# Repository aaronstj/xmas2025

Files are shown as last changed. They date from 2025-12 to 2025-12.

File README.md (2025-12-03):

# xmas2025

This is the code and schematics/PCB design for the 2025 Christmas ornament.

The ornament runs on an ATTINY85 microcontroller running the Micronucleus bootloader.  The code runs on the Arduino platform using the ATTinyCore.

## The top of the ornament looks like a USB?
It is! You can reprogram the ornament through the usb.  Download the ATTinyCore for Arduino, set your board to "ATTiny85 (Micronucleus/Digispark)".  When uploading new code, insert the ESB end of the ornament into your USB port, component-side up - it's not quite the same right size, so it may take some wiggling and careful holding.  You will likely need to use `Zadig` to install the `libusbK` driver.

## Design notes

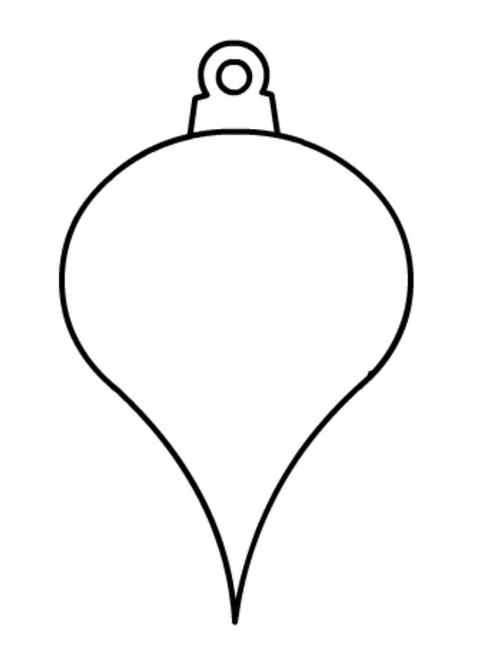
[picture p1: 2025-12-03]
ornament.png

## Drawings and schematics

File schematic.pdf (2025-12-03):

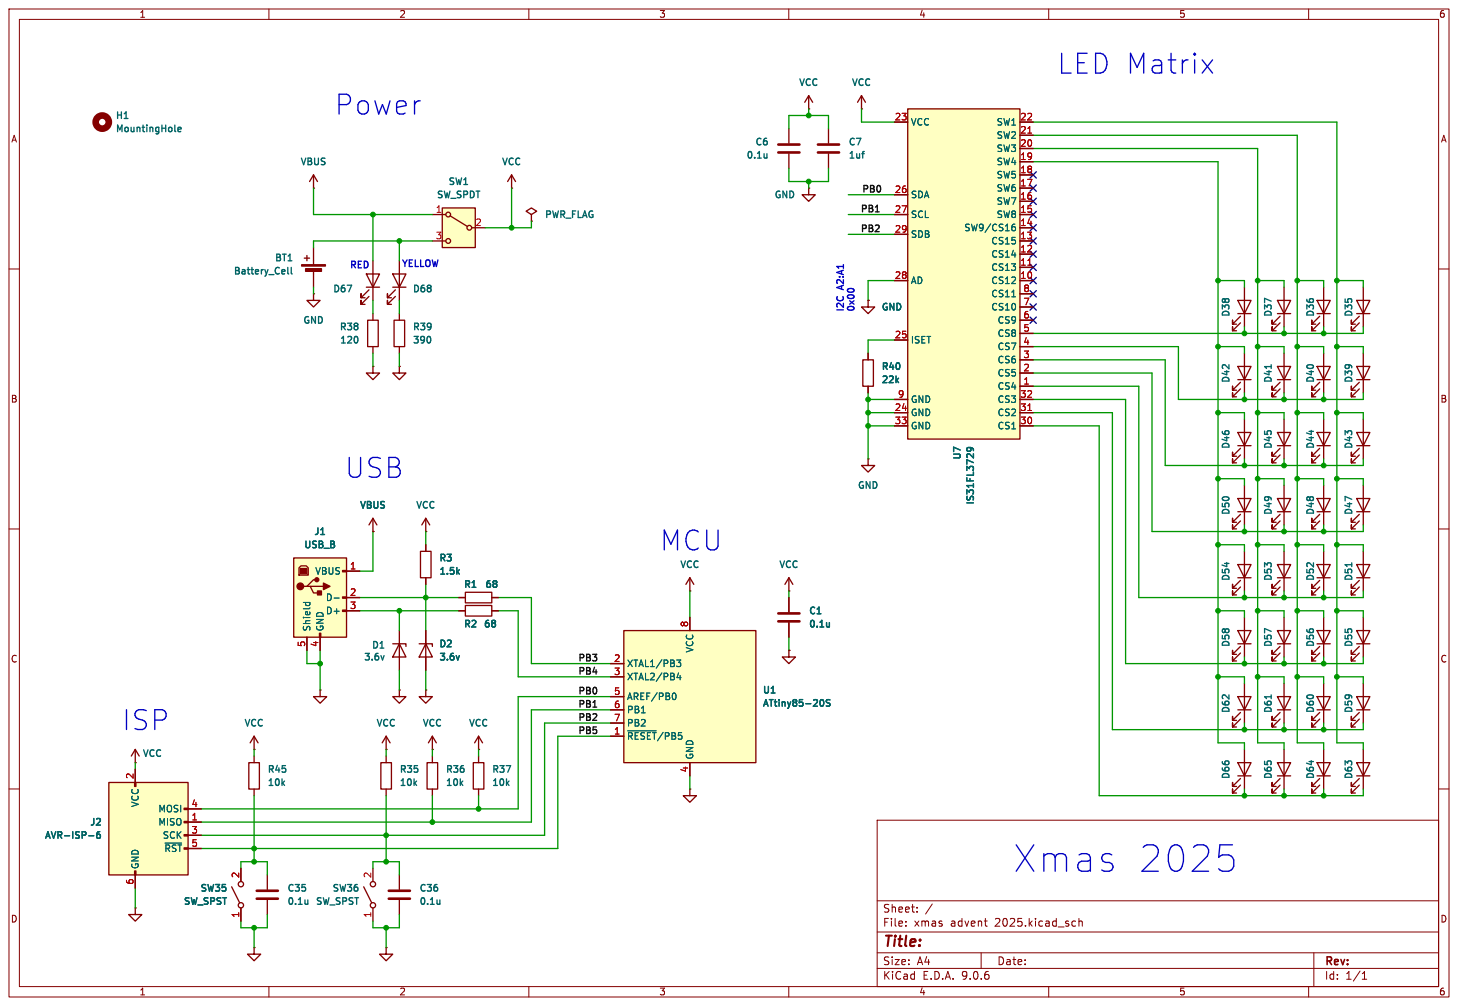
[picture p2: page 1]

Id: 1/1 Title: File: xmas advent 2025.kicad_sch Sheet: / R35

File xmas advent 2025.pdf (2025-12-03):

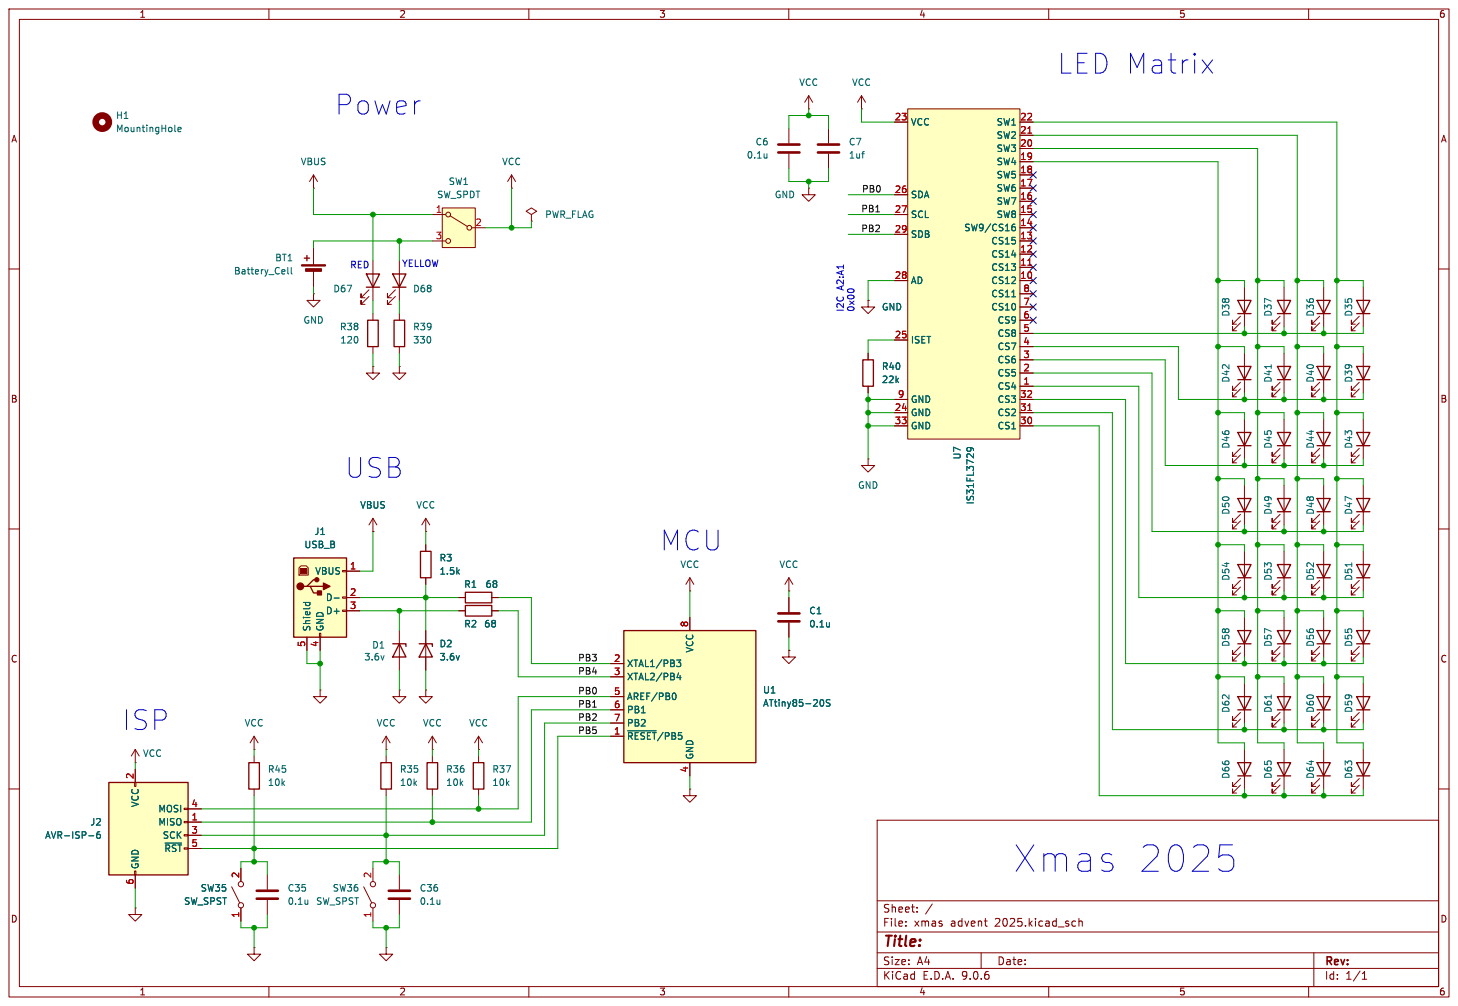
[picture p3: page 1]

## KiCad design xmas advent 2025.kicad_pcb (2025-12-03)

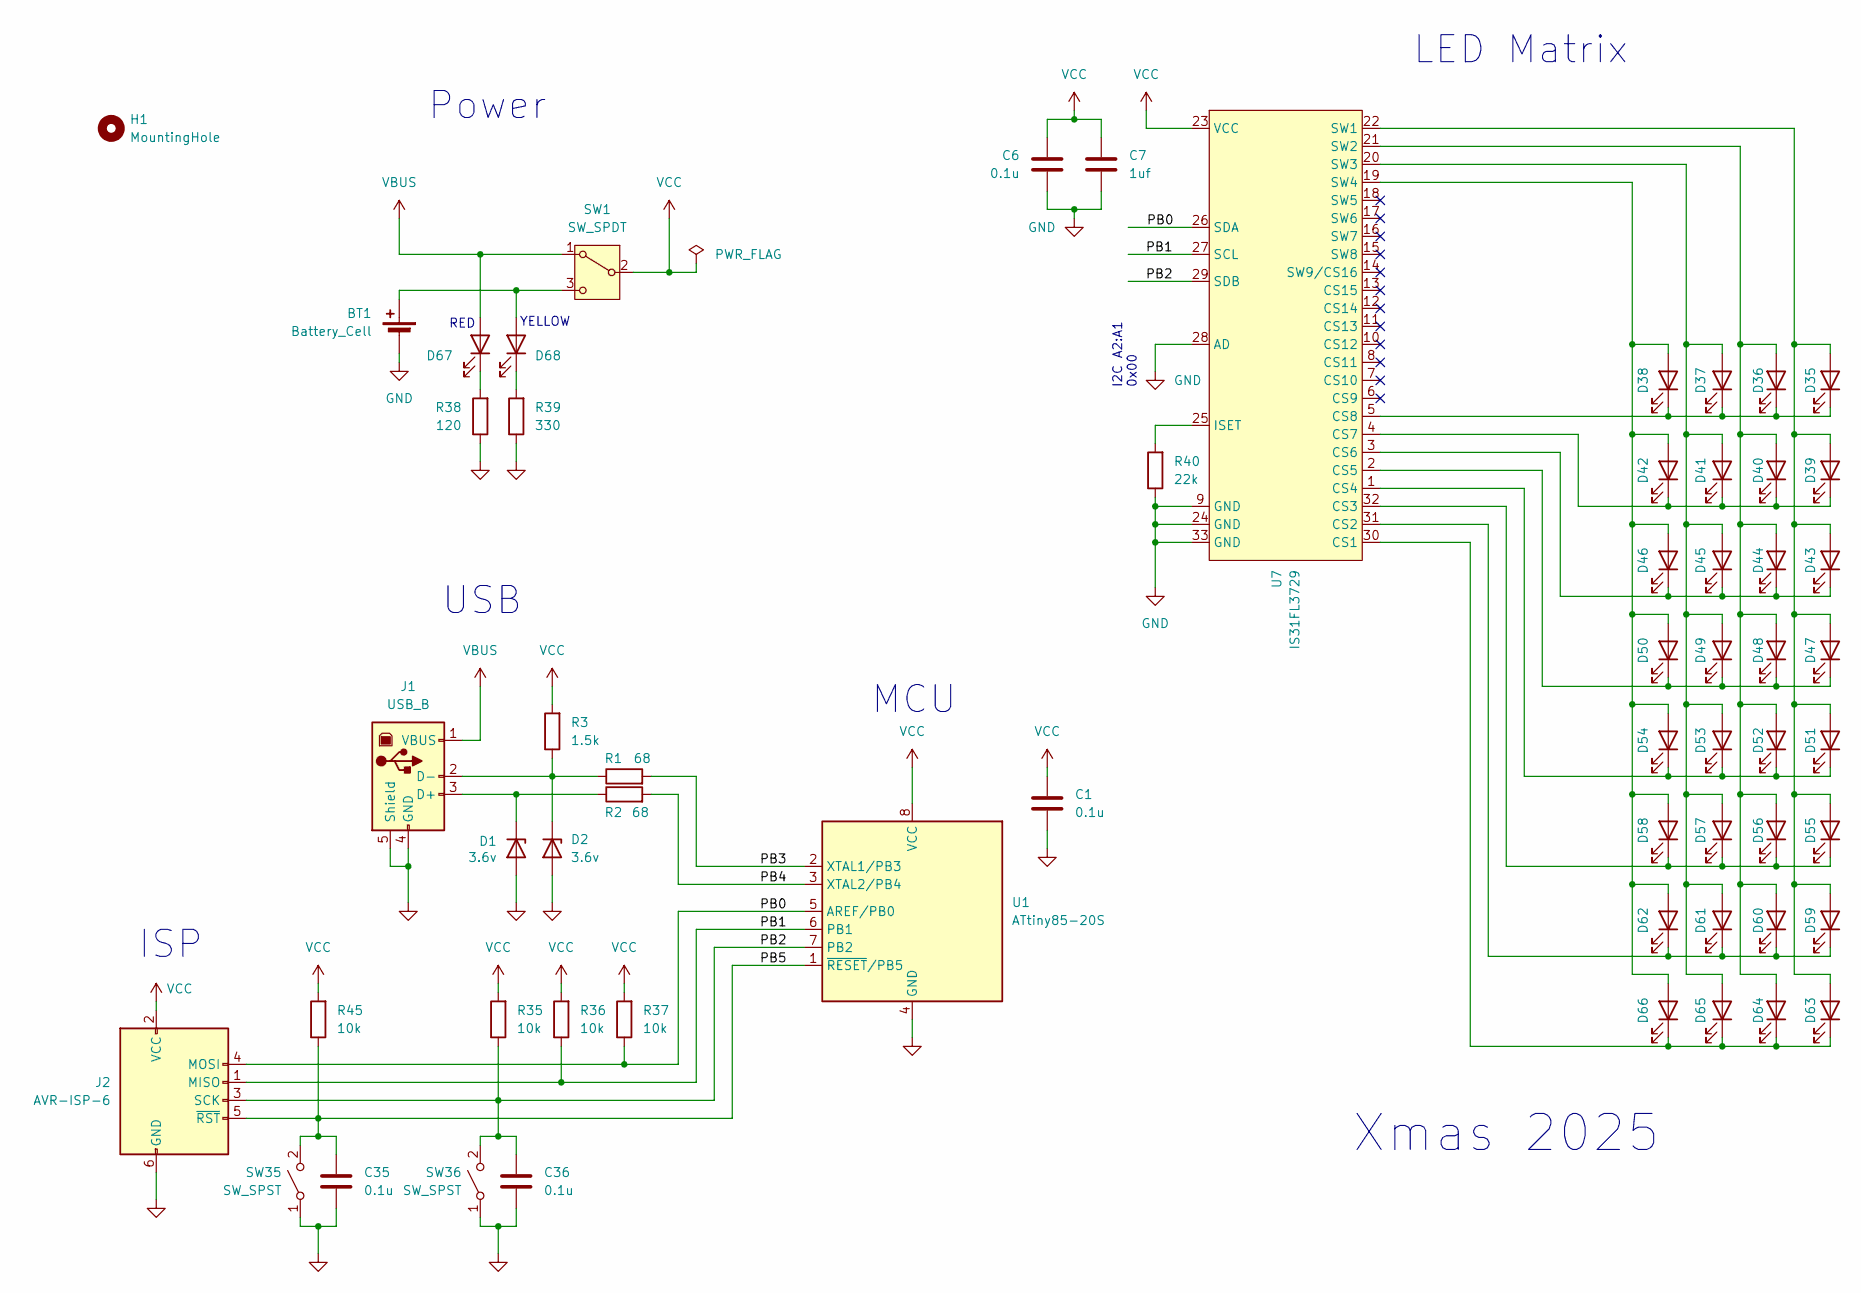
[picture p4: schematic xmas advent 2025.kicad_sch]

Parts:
BT1: Battery_Cell; BATTCOM_20MM_PTH
C1, C6, C35, C36: 0.1u; C_0402_1005Metric
C7: 1uf; C_0402_1005Metric
D1, D2: 3.6v; D_SOD-123
D35, D36, D37, D38, D39, D40, D41, D42, D43, D44, D45, D46, D47, D48, D49, D50, D51, D52, D53, D54, D55, D56, D57, D58, D59, D60, D61, D62, D63, D64, D65, D66: LED; LED_0805_2012Metric
D67: RED; LED_0603_1608Metric
D68: Yellow; LED_0603_1608Metric
H1: MountingHole; MountingHole_3mm
J1: USB_B; CONN-USB-A-PCB-TRACES
J2: AVR-ISP-6; PinHeader_2x03_P2.54mm_Vertical
R1, R2: 68; R_0402_1005Metric
R3: 1.5k; R_0402_1005Metric
R35, R36, R37, R45: 10k; R_0402_1005Metric
R38: 120; R_0402_1005Metric
R39: 330; R_0402_1005Metric
R40: 22k; R_0402_1005Metric
SW1: SW_SPDT; SW_500SSP1S2M2QEA
SW35, SW36: SW_SPST; SW_Push_1P1T_XKB_TS-1187A
U1: ATtiny85-20S; SOIC-8W_5.3x5.3mm_P1.27mm
U7: IS31FL3729; QFN-32-1EP_4x4mm_P0.4mm_EP2.65x2.65mm_ThermalVias

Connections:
/PB0: J2.4 (MOSI), R37.1, U1.5 (AREF/PB0), U7.26 (SDA)
/PB1: J2.1 (MISO), R36.1, U1.6 (PB1), U7.27 (SCL)
/PB2: C36.1, J2.3 (SCK), R35.1, SW36.2 (B), U1.7 (PB2), U7.29 (SDB)
/PB3: R1.2, U1.2 (XTAL1/PB3)
/PB4: R2.2, U1.3 (XTAL2/PB4)
/PB5: C35.1, J2.5 (~RST), R45.1, SW35.2 (B), U1.1 (~RESET/PB5)
GND: BT1.2 (-), C1.2, C6.1, C7.2, C35.2, C36.2, D1.2 (A), D2.2 (A), J1.4 (GND), J1.5 (Shield), J2.6 (GND), R38.1, R39.1, R40.1, SW35.1 (A), SW36.1 (A), U1.4 (GND), U7.9 (GND), U7.24 (GND), U7.28 (AD), U7.33 (GND)
unnamed: BT1.1 (+), D68.2 (A), SW1.3 (C)
unnamed: D1.1 (K), J1.3 (D+), R2.1
unnamed: D2.1 (K), J1.2 (D-), R1.1, R3.1
unnamed: D35.2 (A), D39.2 (A), D43.2 (A), D47.2 (A), D51.2 (A), D55.2 (A), D59.2 (A), D63.2 (A), U7.22 (SW1)
unnamed: D35.1 (K), D36.1 (K), D37.1 (K), D38.1 (K), U7.5 (CS8)
unnamed: D36.2 (A), D40.2 (A), D44.2 (A), D48.2 (A), D52.2 (A), D56.2 (A), D60.2 (A), D64.2 (A), U7.21 (SW2)
unnamed: D37.2 (A), D41.2 (A), D45.2 (A), D49.2 (A), D53.2 (A), D57.2 (A), D61.2 (A), D65.2 (A), U7.20 (SW3)
unnamed: D38.2 (A), D42.2 (A), D46.2 (A), D50.2 (A), D54.2 (A), D58.2 (A), D62.2 (A), D66.2 (A), U7.19 (SW4)
unnamed: D39.1 (K), D40.1 (K), D41.1 (K), D42.1 (K), U7.4 (CS7)
unnamed: D43.1 (K), D44.1 (K), D45.1 (K), D46.1 (K), U7.3 (CS6)
unnamed: D47.1 (K), D48.1 (K), D49.1 (K), D50.1 (K), U7.2 (CS5)
unnamed: D51.1 (K), D52.1 (K), D53.1 (K), D54.1 (K), U7.1 (CS4)
unnamed: D55.1 (K), D56.1 (K), D57.1 (K), D58.1 (K), U7.32 (CS3)
unnamed: D59.1 (K), D60.1 (K), D61.1 (K), D62.1 (K), U7.31 (CS2)
unnamed: D63.1 (K), D64.1 (K), D65.1 (K), D66.1 (K), U7.30 (CS1)
unnamed: D67.1 (K), R38.2
unnamed: D68.1 (K), R39.2
unnamed: R40.2, U7.25 (ISET)
VBUS: D67.2 (A), J1.1 (VBUS), SW1.1 (A)
VCC: C1.1, C6.2, C7.1, J2.2 (VCC), R3.2, R35.2, R36.2, R37.2, R45.2, SW1.2 (B), U1.8 (VCC), U7.23 (VCC)

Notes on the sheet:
USB
Power
LED Matrix
ISP
YELLOW
RED
Xmas 2025
I2C A2:A1 0x00
MCU

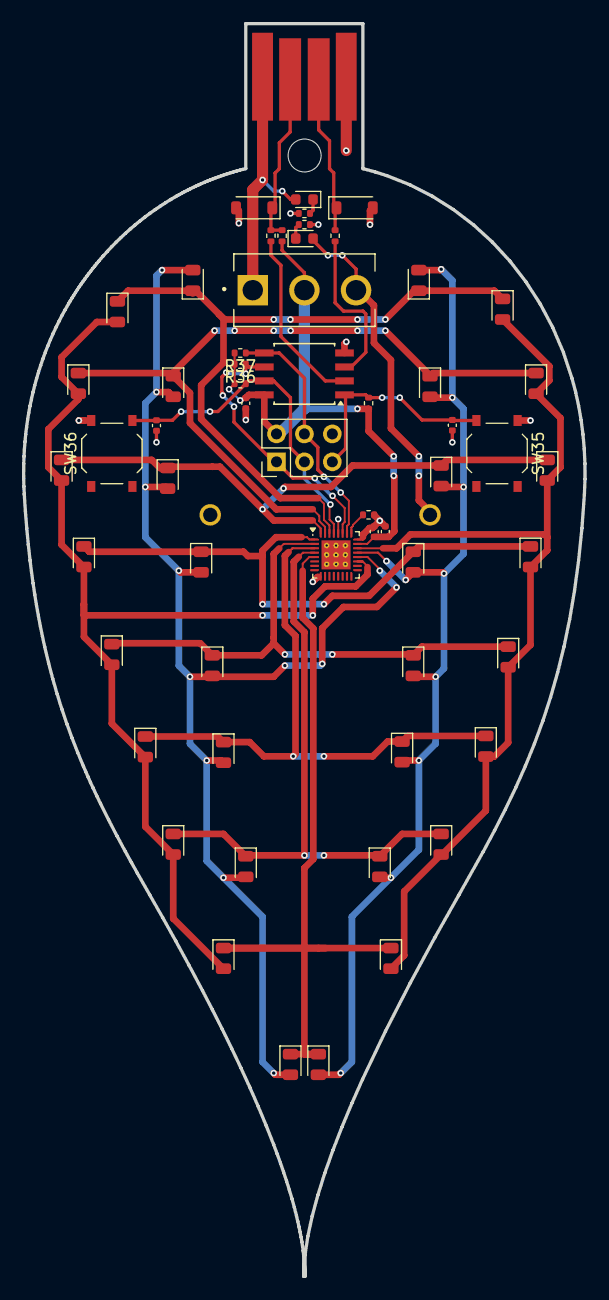
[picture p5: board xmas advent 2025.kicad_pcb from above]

Board: 2 copper layers, 51.1 x 114.0 mm, 60 parts (1 on the bottom side), 27 nets.

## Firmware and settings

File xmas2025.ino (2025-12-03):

// Xmas 2025 Ornament
// This code released into the public domain by Aaron St. John

#include <SoftWire.h>

#include <avr/sleep.h>
#include <avr/power.h>
#include <avr/wdt.h>

#define adc_disable() (ADCSRA &= ~(1<<ADEN)) // disable ADC (before power-off)
#define adc_enable()  (ADCSRA |=  (1<<ADEN)) // re-enable ADC

#define SDA_PORT PB0
#define SCL_PORT PB1
#define SDB_PORT PB2
#define NEXT_BUTTON_PIN PB2 // Yes, same as SDB.  That's why the lights shut off when you press the button

const uint8_t I2C_ADDR = 0b0110100;

uint8_t swTxBuffer[16];
uint8_t swRxBuffer[16];

#define NUM_ROWS 8
#define NUM_COLS 4

#define NUM_ANIMATIONS 7

// I really should define all of these as constants, but I only got to a few
#define FALLING_STAR_SPEED 0x28
#define BACK_AND_FORTH_FADE_SPEED 0x30

uint8_t matrix[NUM_ROWS][NUM_COLS];

SoftWire i2c(SDA_PORT, SCL_PORT);

byte saveADCSRA; // variable to save the content of the ADC for later. if needed.

void setup() {
  // Set up the watchdog timer
  adc_disable();
  resetWatchDog();

  // Button pin to input
  pinMode(NEXT_BUTTON_PIN, INPUT);

  // Reset the LED driver
  pinMode(SDB_PORT, OUTPUT);
  digitalWrite(SDB_PORT, LOW);

  // Set up the I2C library
  i2c.setTxBuffer(swTxBuffer, sizeof(swTxBuffer));
  i2c.setRxBuffer(swRxBuffer, sizeof(swRxBuffer));
  i2c.setDelay_us(0);
  i2c.setTimeout(1000);
  i2c.begin();
  
  // Row scale register
  for(int indexRegister = 0x90; indexRegister <= 0x9F; indexRegister++) {
      writeLedMatrixRegister(indexRegister, 0x80);
  }

  writeLedMatrixRegister(0xA0, 0b00010001); // Configuration register  
  writeLedMatrixRegister(0xA1, 0x01); // Global current register

  // Turn the LED driver on
  digitalWrite(SDB_PORT, HIGH);

  setupAnimation();  
}

// Writes a register to the LED matrix
void writeLedMatrixRegister(uint8_t reg, uint8_t data) {
  i2c.beginTransmission(I2C_ADDR);
  i2c.write(reg);
  i2c.write(data);
  i2c.endTransmission();
}

int frame = 0;
int animation = 0;
bool lastNextButton = false;

// the loop function runs over and over again forever
void loop() {
  // Count frames to time some of the animations
  frame++; 

  // The button is held high, and pressing the button ties it to ground
  bool thisNextButton = !digitalRead(NEXT_BUTTON_PIN);

  // On release, switch animations
  // (should probably do it on press so the switchover is less noticible, but here we are...)
  if(lastNextButton & ! thisNextButton) {
    animation = (animation + 1) % NUM_ANIMATIONS;
    setupAnimation();
  }

  runAnimation();

  // Write the LED matrix to the LED controller
  for(int indexRow = 0; indexRow < NUM_ROWS; indexRow++) {
      for(int indexCol = 0; indexCol < NUM_COLS; indexCol++) {
        writeLedMatrixRegister((NUM_COLS - indexCol - 1) * 0x10 + indexRow + 1, matrix[indexRow][indexCol]);
      }
    }

  // update the button state
  lastNextButton = thisNextButton;

  sleepNow ();
}

void setupAnimation() {
  // Set up the animation
  switch(animation) {
    // falling stars
    case 0:
      for(int indexRow = 0; indexRow < NUM_ROWS; indexRow++) {
        for(int indexCol = 0; indexCol < NUM_COLS; indexCol++) {
          matrix[indexRow][indexCol] = 0;
        }
      }
      break;

    // up and down
    case 1:
      for(int indexRow = 0; indexRow < NUM_ROWS; indexRow++) {
        for(int indexCol = 0; indexCol < NUM_COLS; indexCol++) {
          matrix[indexRow][indexCol] = random(0xff);
        }
      }
      break;

    // random stars
    case 2:
      for(int indexRow = 0; indexRow < NUM_ROWS; indexRow++) {
        for(int indexCol = 0; indexCol < NUM_COLS; indexCol++) {
          matrix[indexRow][indexCol] = 0x00;
        }
      }
      break;

    // chasers
    case 3:
      for(int indexRow = 0; indexRow < NUM_ROWS; indexRow++) {
        for(int indexCol = 0; indexCol < NUM_COLS; indexCol++) {
          matrix[indexRow][indexCol] = (indexRow + indexCol) % 4 * (0xFF/4);
        }
      }
      break;

    // chasers 2
    case 4:
      for(int indexRow = 0; indexRow < NUM_ROWS; indexRow++) {
        for(int indexCol = 0; indexCol < NUM_COLS; indexCol++) {
          matrix[indexRow][indexCol] = (indexRow + indexCol) % 4 * (0xFF/4);
        }
      }
      break;

    // back and forth
    case 5:
      for(int indexRow = 0; indexRow < NUM_ROWS; indexRow++) {
        for(int indexCol = 0; indexCol < NUM_COLS; indexCol++) {
          matrix[indexRow][indexCol] = 0;
        }
      }
      break;

       // on
    case 6:
      for(int indexRow = 0; indexRow < NUM_ROWS; indexRow++) {
        for(int indexCol = 0; indexCol < NUM_COLS; indexCol++) {
          matrix[indexRow][indexCol] = 0xFF;
        }
      }
      break;
  }
}

void runAnimation() {
  // Do the animation
  switch(animation) {
    // falling stars
    case 0:
      for(int indexCol = 0; indexCol < NUM_COLS; indexCol++) {        
        if(random() % 10 == 0) {
          matrix[0][indexCol] = 0xFF;
        } else {
          if(matrix[0][indexCol] > FALLING_STAR_SPEED) {
            matrix[0][indexCol] = matrix[0][indexCol] - FALLING_STAR_SPEED;
          }
        }
      }

      for(int indexRow = NUM_ROWS - 1; indexRow >= 1; indexRow--) {
        for(int indexCol = 0; indexCol < NUM_COLS; indexCol++) {
          matrix[indexRow][indexCol] = matrix[indexRow - 1][indexCol];
        }
      }        
      
      break;

    case 1:
      for(int indexRow = 0; indexRow < NUM_ROWS; indexRow++) {
        for(int indexCol = 0; indexCol < NUM_COLS; indexCol++) {
          if(matrix[indexRow][indexCol] % 2) {
            if(matrix[indexRow][indexCol] > 0x04) {
              matrix[indexRow][indexCol] -= 0x04;
            } else {
              matrix[indexRow][indexCol] = 0x00;
            }
          } else {
            if(matrix[indexRow][indexCol] < 0xFF - 0x04) {
              matrix[indexRow][indexCol] += 0x04;
            } else {
              matrix[indexRow][indexCol] = 0xFF;
            }
          }  
        }
      }
      break;

    // random stars
    case 2:
      for(int indexRow = 0; indexRow < NUM_ROWS; indexRow++) {
        for(int indexCol = 0; indexCol < NUM_COLS; indexCol++) {
          if(random(25) == 0) {
            matrix[indexRow][indexCol] = 0xFF;
          } else if (matrix[indexRow][indexCol] > 0x04)
            matrix[indexRow][indexCol] -= 0x10;
        }
      }
      break;

    // chasers
    case 3:
      for(int indexRow = 0; indexRow < NUM_ROWS; indexRow++) {
        for(int indexCol = 0; indexCol < NUM_COLS; indexCol++) {
          matrix[indexRow][indexCol] -= 0x28;
        }
      }
      break;

    // chaser 2
    case 4:
      for(int indexRow = 0; indexRow < NUM_ROWS; indexRow++) {
        for(int indexCol = 0; indexCol < NUM_COLS; indexCol++) {
          if(indexRow % 2) {
            matrix[indexRow][indexCol] -= 0x28;
          } else {
            matrix[indexRow][indexCol] += 0x28;
          }
        }
      }
      break;

    // back and forth
    case 5:
      // even rows
      for(int indexRow = 0; indexRow < NUM_ROWS; indexRow += 2) {        
        if(frame * 11 % 17 == indexRow) {
          matrix[indexRow][0] = 0xFF;
        } else {
          if(matrix[indexRow][0] > BACK_AND_FORTH_FADE_SPEED) {
            matrix[indexRow][0] = matrix[indexRow][0] - BACK_AND_FORTH_FADE_SPEED;
          }
        }
      }

      // odd rows
      for(int indexRow = 1; indexRow < NUM_ROWS; indexRow += 2) {        
        if(frame * 11 % 19 == indexRow) {
          matrix[indexRow][NUM_COLS - 1] = 0xFF;
        } else {
          if(matrix[indexRow][NUM_COLS - 1] > BACK_AND_FORTH_FADE_SPEED) {
            matrix[indexRow][NUM_COLS - 1] = matrix[indexRow][NUM_COLS - 1] - BACK_AND_FORTH_FADE_SPEED;
          }
        }
      }

      if(frame % 1 == 0) {
        for(int indexRow = 0; indexRow < NUM_ROWS; indexRow++) {
          if(indexRow % 2 == 0) {
            // even rows
            for(int indexCol = NUM_COLS - 1; indexCol >= 1; indexCol--) {
              matrix[indexRow][indexCol] = matrix[indexRow][indexCol - 1];
            }
          } else {
            // odd rows
            for(int indexCol = 0; indexCol < NUM_COLS - 1; indexCol++) {
              matrix[indexRow][indexCol] = matrix[indexRow][indexCol + 1];
            }
          }
        }        
      }
      break;
  }  

  // For the last animation, don't do anything.  Just leave the lights on
}

// Shamelessly stolen from the internet
void sleepNow ()
{
  set_sleep_mode ( SLEEP_MODE_PWR_DOWN ); // set sleep mode Power Down
  saveADCSRA = ADCSRA;                    // save the state of the ADC. We can either restore it or leave it turned off.
  ADCSRA = 0;                             // turn off the ADC
  power_all_disable ();                   // turn power off to ADC, TIMER 1 and 2, Serial Interface
  
  noInterrupts ();                        // turn off interrupts as a precaution
  resetWatchDog ();                       // reset the WatchDog before beddy bies
  sleep_enable ();                        // allows the system to be commanded to sleep
  interrupts ();                          // turn on interrupts
  
  sleep_cpu ();                           // send the system to sleep, night night!

  sleep_disable ();                       // after ISR fires, return to here and disable sleep
  power_all_enable ();                    // turn on power to ADC, TIMER1 and 2, Serial Interface
  
  // ADCSRA = saveADCSRA;                 // turn on and restore the ADC if needed. Commented out, not needed.
  
} // end of sleepNow ()

void resetWatchDog ()
{
  MCUSR = 0;
  WDTCR = bit ( WDCE ) | bit ( WDE ) | bit ( WDIF ); // allow changes, disable reset, clear existing interrupt
  WDTCR = bit ( WDIE ) /*| bit ( WDP2 )| bit ( WDP1 )*/; // set WDIE ( Interrupt only, no Reset ) and 15 millisecond TimeOut
                                                    
  wdt_reset ();                            // reset WDog to parameters
  
} // end of resetWatchDog ()

ISR ( WDT_vect )
{
  wdt_disable ();                           // until next time....
} // end of ISR
